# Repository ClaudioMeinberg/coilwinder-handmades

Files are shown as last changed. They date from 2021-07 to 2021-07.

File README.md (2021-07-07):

# Bobinadeira Automática Handmades

Projeto coletivo de bobinadeira automática com uso direcionado a bobinas para captadores e transformadores de tensão.

## Discussão

A discussão do projeto está centralizada no fórum [Handmades](http://www.handmades.com.br/forum/) tópico [Coil Winder](http://www.handmades.com.br/forum/index.php?topic=12323.0)

## Licença

GNU General Public License v3.0

**Características**
Pode copiar
Pode alterar
Tem que manter o código público
Tem que manter a mesma licença

## Versões

### Original

> Baseado no projeto [DIY-Arduino-based-Guitar-Pickup-Coil-Winder](https://github.com/sandy9159/DIY-Arduino-based-Guitar-Pickup-Coil-Winder)

- [x] Arduino uno ou compatível
- [x] Display HMI
- [ ] Display I2C

### Custo reduzido

> Substituição do display HMI por I2C e inclusão de controles

- [x] Arduino uno ou compatível
- [ ] Display HMI Nextion
- [x] Display I2C

### Hardcore

> Versão minimalista do arduino baseado no projeto [Arduino 100 Noção](https://garoa.net.br/wiki/Arduino_100_No%C3%A7%C3%A3o#Esquema_de_montagem_2)

- [ ] Arduino uno ou compatível
- [ ] Display HMI Nextion
- [x] Display I2C

## Características técnicas
### Motores
Para manter as facilidades das bibliotecas utilizadas no projeto inicial, é necessário o de motores de passo para o enrolador e controlador da guia.

Dado a limitação dos drivers sugerido, corrente e tensão máximas são **2,5A** e **45V** respectivamente.

#### Driver
O driver sugerido para todas as versões é o **[DRV8825](https://www.ti.com/lit/ds/symlink/drv8825.pdf?ts=1625675683245)** que conta com limitador de corrente ajustável e proteção contra superaquecimento.

**Tensão de operação**: 8,2V a 45V
**Corrente fornecida**: 2,5A por bobina com ventilação forçada (24V e 25°C)
**Resoluções de passo**: 6 (1/1, 1/2, 1/4, 1/8, 1/16, 1/32)

## Lista de Componentes

    Valores baseados em pesquisa rápida, componentes avulsos, unitários, no Brasil e com nota fiscal

| Item | Quantidade | Vlr Un. (R$) | Total (R$) | Original | Custo Reduzido |
|--|--|--|--|--|--|
|Arduino Nano | 1 | 35,00| 35,00 | X | X |
|Acoplamento Flexível 5 X 8mm | 1 | 15,00| 15,00 | X | X |
|Fuso Trapezoidal 150mm Com Castanha | 1 | 25,00| 25,00 | X | X |
|Guia Linear 8x150mm | 2 | 15,00| 30,00 | X | X |
|Rolamento Linear Lmf8uu | 2 | 20,00 | 40,00 | X | X |
|Suporte para guia linear | 2 | 15,00| 30,00 | X | X |
|Driver DRV8825 | 2 | 20,00| 40,00 | X | X |
|Motor de passo Nema 17 - 4,2 Kgf.cm / 1,7A | 1 | 60,00| 60,00 | X | X |
|Motor de Passo Nema 17 - 6,5 Kgf.cm / 1,2A | 1 | 100,00 | 100,00 | X | X |
|Fonte 9V 2A | 1 | 30,00 | 30,00 | X | X |
|Display LCD HMI TFT Nextion 2.4 | 1 | 235,00 | 235,00 | X |  |
|Display OLED 0.96 I2C | 1 | 30,00 | 30,00 |  | X |
||||**Total**|640,00|435,00|

### Peças impressas em 3D
Suporte para nema 17 guia
Carrinho guia

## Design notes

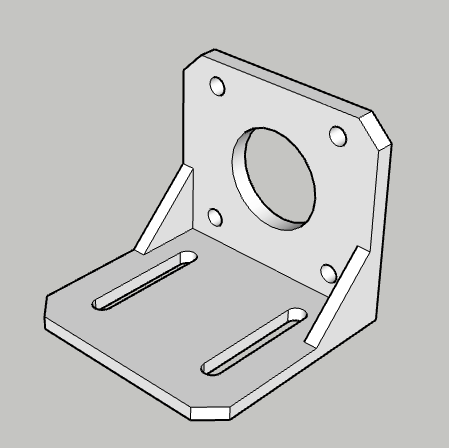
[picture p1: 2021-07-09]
3d-models/Nema17_plate.png

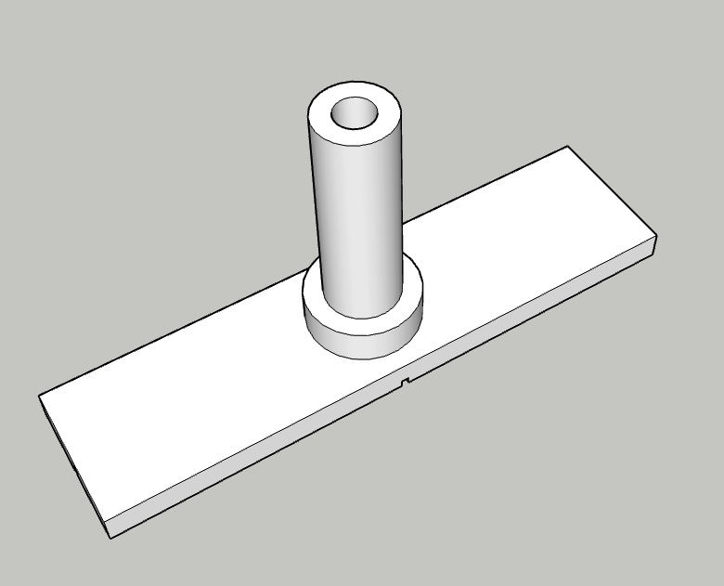
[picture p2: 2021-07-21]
3d-models/suporte_do_carretel.png

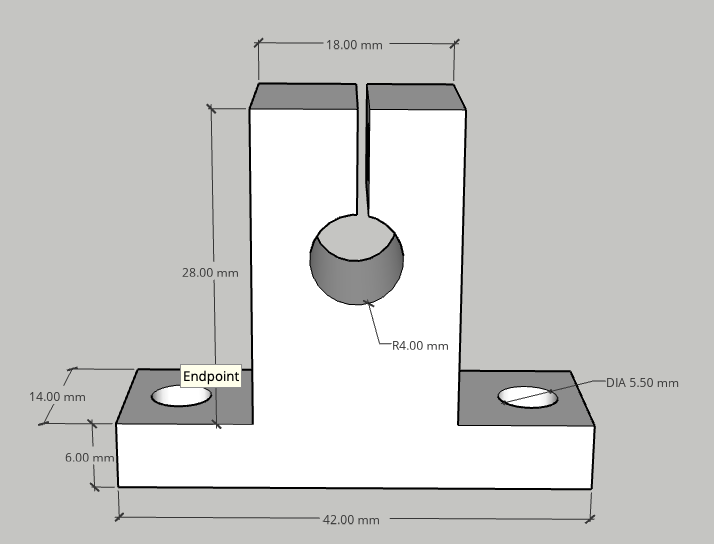
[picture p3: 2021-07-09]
3d-models/suporte_da_guia.png

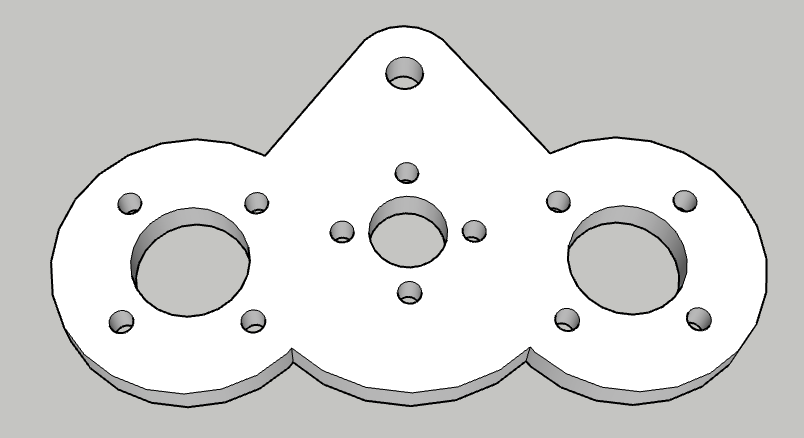
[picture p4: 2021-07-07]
3d-models/carrinho_guia.png

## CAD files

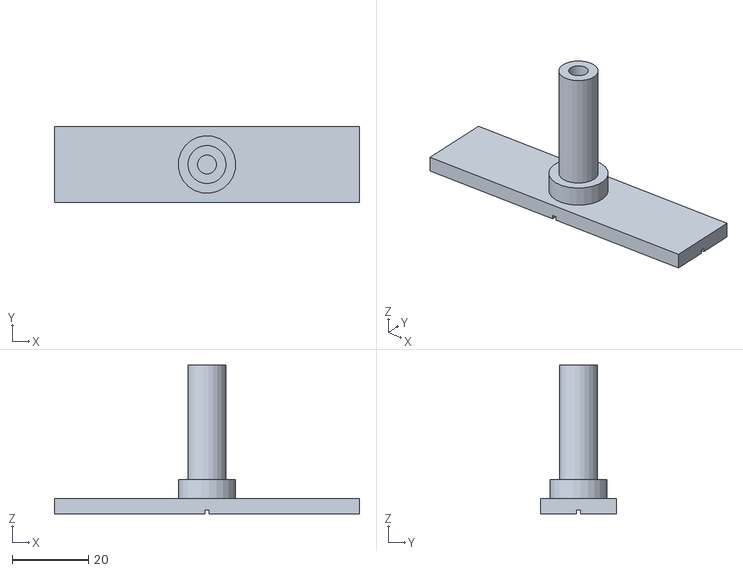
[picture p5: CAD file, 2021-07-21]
3d-models/suporte_do_carretel.stl
80.0 x 20.0 x 39.0

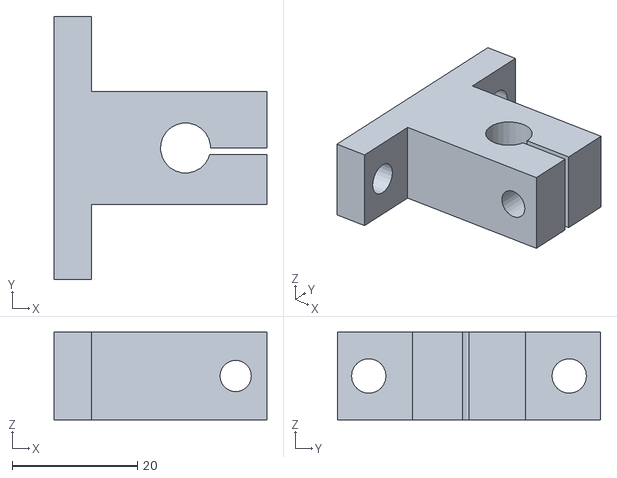
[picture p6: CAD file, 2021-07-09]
3d-models/suporte_da_guia.stl
34.0 x 42.0 x 14.0

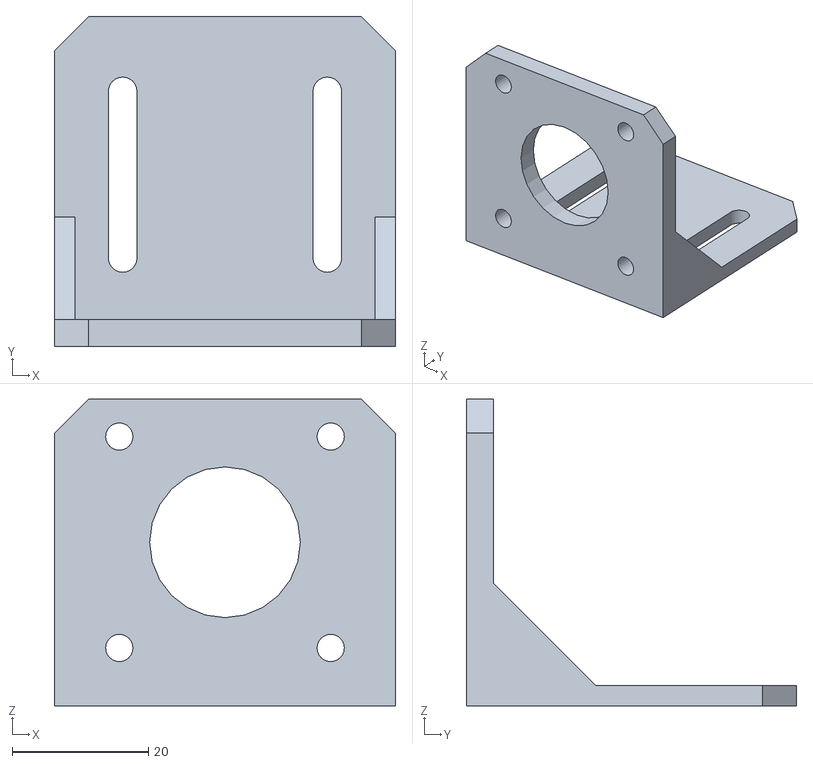
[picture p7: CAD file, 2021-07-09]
3d-models/Nema17_plate.stl
50.0 x 48.4 x 45.0

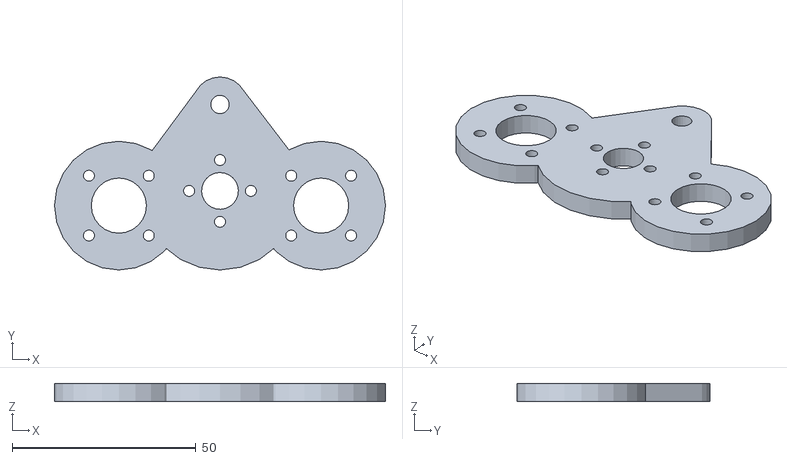
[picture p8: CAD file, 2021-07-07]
3d-models/carrinho_guia.stl
90.0 x 52.5 x 5.00

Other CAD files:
3d-models/Nema17_plate.skp
3d-models/carrinho_guia.skp
3d-models/suporte_da_guia.skp
3d-models/suporte_do_carretel.skp

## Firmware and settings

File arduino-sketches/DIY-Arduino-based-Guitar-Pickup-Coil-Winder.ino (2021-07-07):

/*
File downloaded from 
https://github.com/sandy9159/DIY-Arduino-based-Guitar-Pickup-Coil-Winder/blob/main/Guitar%20pickup%20winder.ino

07-JUL-2021
*/
#include <Stepper.h>
#include <Arduino.h>
#include "BasicStepperDriver.h"
#include "MultiDriver.h"
#include "SyncDriver.h"
#include <SoftwareSerial.h>
SoftwareSerial mySerial(2, 3); // RX, TX
int A = 0;
int B = 0;
int C = 0;
int L = 40;
int state = 0;
int EN = 12;
String message;
int QTY, numMessages, endBytes;
byte inByte;
int flag = 0;



#define DIR_X 14
#define STEP_X 15
#define DIR_Y 16
#define STEP_Y 17
#define MICROSTEPS 16
#define MOTOR_STEPS 200

int count = 0;
BasicStepperDriver stepperX(MOTOR_STEPS, DIR_X, STEP_X);
BasicStepperDriver stepperY(MOTOR_STEPS, DIR_Y, STEP_Y);
SyncDriver controller(stepperX, stepperY);


void setup()
{ 
  pinMode(EN,OUTPUT);
  digitalWrite(EN,HIGH);
  numMessages, endBytes = 0;
  Serial.begin(9600);
  mySerial.begin(9600);
  stepperX.begin(250, MICROSTEPS);
  stepperY.begin(250, MICROSTEPS);
  delay(500);
}

void loop()
{
  data();
  if (A > 0 && B > 0 && C > 0) {
    digitalWrite(EN,LOW);
if (count <= C){

  
for (int i = 0; i <= L; i++){
  if (count > C){
break;
  }
controller.rotate(360,40);
mySerial.print("n2.val=");
mySerial.print(count);
mySerial.write(0xff);
mySerial.write(0xff);
mySerial.write(0xff);
count++;  
}

for (int i = 0; i <= L; i++){
if (count > C){
break;
  }
controller.rotate(360,-40);  
mySerial.print("n2.val=");
mySerial.print(count);
mySerial.write(0xff);
mySerial.write(0xff);
mySerial.write(0xff);
count++;
}
}   
}
}


void data() {
    if (state == 0) {
      if (numMessages == 1) { //Did we receive the anticipated number of messages? In this case we only want to receive 1 message.
        A = QTY;
        Serial.println(A);//See what the important message is that the Arduino receives from the Nextion
        numMessages = 0; //Now that the entire set of data is received, reset the number of messages received
        state = 1;
      }
    }

    if (state == 1) {
      if (numMessages == 1) { //Did we receive the anticipated number of messages? In this case we only want to receive 1 message.
        B = QTY;
        Serial.println(B);//See what the important message is that the Arduino receives from the Nextion
        numMessages = 0; //Now that the entire set of data is received, reset the number of messages received
        state = 2;
      }
    }

if (state == 2) {
      if (numMessages == 1) { //Did we receive the anticipated number of messages? In this case we only want to receive 1 message.
        C = QTY;
        Serial.println(C);//See what the important message is that the Arduino receives from the Nextion
        numMessages = 0; //Now that the entire set of data is received, reset the number of messages received
        state = 0;
      }
    }
    






    if (mySerial.available()) { //Is data coming through the serial from the Nextion?
      inByte = mySerial.read();

      // Serial.println(inByte); //See the data as it comes in

      if (inByte > 47 && inByte < 58) { //Is it data that we want to use?
        message.concat(char(inByte)); //Cast the decimal number to a character and add it to the message
      }
      else if (inByte == 255) { //Is it an end byte?
        endBytes = endBytes + 1; //If so, count it as an end byte.
      }

      if (inByte == 255 && endBytes == 3) { //Is it the 3rd (aka last) end byte?
        QTY = message.toInt(); //Because we have now received the whole message, we can save it in a variable.
        message = ""; //We received the whole message, so now we can clear the variable to avoid getting mixed messages.
        endBytes = 0; //We received the whole message, we need to clear the variable so that we can identify the next message's end
        numMessages  = numMessages + 1; //We received the whole message, therefore we increment the number of messages received.

        //Now lets test if it worked by playing around with the variable.

      }
    }
  }

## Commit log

2021-07-09 fix support model hight
    [suporte_da_guia.skp, suporte_da_guia.stl]
2021-07-21 model: bobbin holder
    [suporte_do_carretel.skp, suporte_do_carretel.stl]
